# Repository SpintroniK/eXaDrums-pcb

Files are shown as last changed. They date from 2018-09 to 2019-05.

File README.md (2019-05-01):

# eXaDrums-pcb

Components list: 

 * MCP3008 x1 (U1) - https://fr.farnell.com/microchip/mcp3008-i-sl/10bit-adc-8-ch-spi-smd-soic16/dp/1292241
 * LMC7660 x1 (U2) - https://fr.farnell.com/texas-instruments/lmc7660im-nopb/convertisseur-dc-dc-charge-pump/dp/1469158
 * TLC2264 x2 (U3, U4) - https://fr.farnell.com/texas-instruments/tlc2264cdr/ampli-op-710khz-0-55v-us-soic/dp/2782837
 * 100k resistors x24 (R1 to 224) - https://fr.farnell.com/multicomp/mcsr08x1003ftl/res-ceramique-100k-1-0-125w-0805/dp/2074335
 * 1M potentiometers x8 (RV1 to RV8) - https://fr.farnell.com/bourns/3314g-2-105e/potentiometre-trimmer-1m-20-1/dp/2328478
 * 10µF capacitors x2 (C1, C2) - https://fr.farnell.com/vishay/tmcp1a106ktrf/condensateur-tantale-10uf-10v/dp/2491435
 * 10µF capacitor x1 (C3) - https://fr.farnell.com/kemet/c0805c106m9racauto/condensateur-10-f-6-3v-20-x7r/dp/2776884
 * 220nF capacitor x1 (C4) - https://fr.farnell.com/yageo/cc0805krx7r7bb224/condensateur-mlcc-x7r-220nf-16v/dp/644183
 * Board-To-Board Connector - https://fr.farnell.com/wurth-elektronik/61304021821/connect-femelle-40-voies-2-rangs/dp/2827916
 * D Sub Connector - https://fr.farnell.com/norcomp/171-025-213r001/sub-d-embase-a-souder-droit-25voies/dp/2294252

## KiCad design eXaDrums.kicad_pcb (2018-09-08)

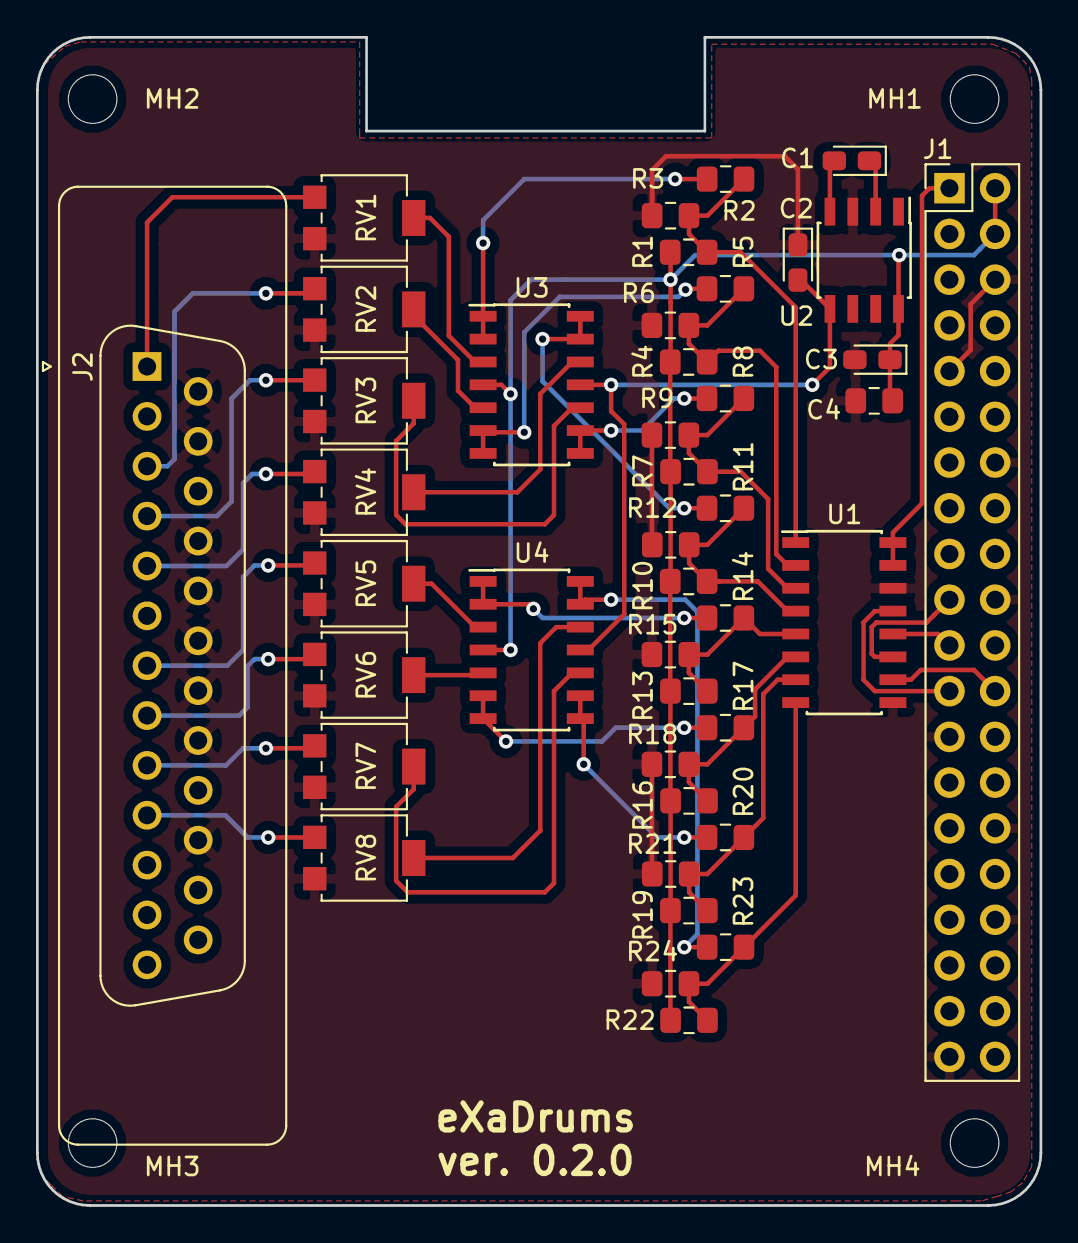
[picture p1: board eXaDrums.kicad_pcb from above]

Board: 2 copper layers, 55.8 x 64.9 mm, 46 parts (0 on the bottom side), 42 nets.

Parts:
C1, C2, C3: 10uF; CP_EIA-2012-12_Kemet-R_Pad1.30x1.05mm_HandSolder
C4: 220nF; C_0805_2012Metric_Pad1.15x1.40mm_HandSolder
J1: Conn_02x20_Odd_Even; PinHeader_2x20_P2.54mm_Vertical
J2: DB25_Female; DSUB-25_Female_Vertical_P2.77x2.84mm
MH1, MH2, MH3, MH4: MountingHole; MountingHole_2.7mm_M2.5
R1, R2, R3, R4, R5, R6, R7, R8, R9, R10, R11, R12, R13, R14, R15, R16, R17, R18, R19, R20, R21, R22, R23, R24: R; R_0805_2012Metric_Pad1.15x1.40mm_HandSolder
RV1, RV2, RV3, RV4, RV5, RV6, RV7, RV8: R_POT; Potentiometer_Bourns_3314G_Vertical
U1: MCP3008; SOIC-16_3.9x9.9mm_P1.27mm
U2: ICL7660; SOIC-8_3.9x4.9mm_P1.27mm
U3, U4: TLC274; SOIC-14_3.9x8.7mm_P1.27mm

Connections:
+3V3: J1.1, U1.15, U1.16
+5V: C3.1, C4.1, J1.2, J1.4, R1.2, R4.2, R7.2, R10.2, R13.2, R16.2, R19.2, R22.2, U2.8, U3.4, U4.4
CLK: J1.23, U1.13
CS0: J1.24, U1.10
GND: C2.1, C3.2, C4.2, J1.6, J1.9, J1.14, J1.20, J1.25, J1.30, J1.34, J1.39, J2.14, J2.15, J2.17, J2.18, J2.19, J2.20, J2.21, J2.23, R3.1, R6.1, R9.1, R12.1, R15.1, R18.1, R21.1, R24.1, RV1.3, RV2.3, RV3.3, RV4.3, RV5.3, RV6.3, RV7.3, RV8.3, U1.9, U1.14, U2.3
MISO: J1.21, U1.12
MOSI: J1.19, U1.11
unnamed: C1.1, U2.2
unnamed: C1.2, U2.4
unnamed: J2.1, RV1.1
unnamed: J2.3, RV2.1
unnamed: J2.4, RV3.1
unnamed: J2.5, RV4.1
unnamed: J2.7, RV5.1
unnamed: J2.8, RV6.1
unnamed: J2.9, RV7.1
unnamed: J2.10, RV8.1
unnamed: R1.1, R2.1, R3.2, U1.1
unnamed: R2.2, U3.1, U3.2
unnamed: R4.1, R5.1, R6.2, U1.2
unnamed: R5.2, U3.6, U3.7
unnamed: R7.1, R8.1, R9.2, U1.3
unnamed: R8.2, U3.8, U3.9
unnamed: R10.1, R11.1, R12.2, U1.4
unnamed: R11.2, U3.13, U3.14
unnamed: R13.1, R14.1, R15.2, U1.5
unnamed: R14.2, U4.1, U4.2
unnamed: R16.1, R17.1, R18.2, U1.6
unnamed: R17.2, U4.6, U4.7
unnamed: R19.1, R20.1, R21.2, U1.7
unnamed: R20.2, U4.8, U4.9
unnamed: R22.1, R23.1, R24.2, U1.8
unnamed: R23.2, U4.13, U4.14
unnamed: RV1.2, U3.3
unnamed: RV2.2, U3.5
unnamed: RV3.2, U3.10
unnamed: RV4.2, U3.12
unnamed: RV5.2, U4.3
unnamed: RV6.2, U4.5
unnamed: RV7.2, U4.10
unnamed: RV8.2, U4.12
Vee: C2.2, U2.5, U3.11, U4.11

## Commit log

2018-09-05 First working prototype. Boards ordered from OSH Park.
    [eXaDrums.kicad_pcb, eXaDrums.sch]
2018-09-08 Version 0.2.0: New board layout, and DB25 connector.
    [eXaDrums.kicad_pcb, eXaDrums.sch]
